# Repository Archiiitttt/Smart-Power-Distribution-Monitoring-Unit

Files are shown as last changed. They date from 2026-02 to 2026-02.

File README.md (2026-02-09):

# Smart Power Distribution & Monitoring Unit ⚡

## 📖 Overview
This project is an industrial-grade **Power Distribution and Monitoring Unit** designed to manage high-voltage DC inputs (up to 40V) for robotic or automotive applications. 

Unlike standard power distribution boards, this unit features **active intelligent monitoring**. It is centered around an **STM32F103 (ARM Cortex-M3)** to sample current and temperature data, providing a hardware platform capable of proactive system shutdown before thermal runaway or over-current events occur.

### 🎯 Key Capabilities
* **Wide Input Range:** Designed to handle **12V–40V DC** input with dedicated surge protection.
* **Smart Protection:** Features **Reverse Polarity Protection** using a P-Channel MOSFET (IRF4905) to minimize voltage drop compared to traditional diode-based solutions.
* **High-Power Switching:** Capable of driving high-current external loads via an **IRFP4468 MOSFET** and a dedicated **TC4427 Gate Driver**.
* **Integrated Telemetry:** Supports power consumption monitoring via a **1mΩ Shunt + INA180 Amplifier** and thermal tracking through a **6-zone NTC matrix**.

---

## ⚙️ System Architecture
The hardware architecture is divided into four main functional stages: **Protection, Regulation, Control, and Actuation**.

### 1. Power Stage
* **Input Protection:** Includes an automotive blade fuse and TVS Diode (D3) to clamp voltage spikes.
* **Reverse Polarity:** Implemented via **IRF4905** (Q1) for high-efficiency protection.
* **Regulation Logic:** Two-stage step-down architecture:
    1.  **Buck Converter (U1 - LM2596S-ADJ):** Steps 40V down to 12V for the Gate Driver.
    2.  **LDO (U2 - AMS1117-3.3):** Steps 12V down to 3.3V for the MCU and sensor suite.

### 2. Control & Sensing
* **Microcontroller:** Powered by an **STM32F103C8Tx** (U5).
* **Current Monitoring:** High-side sensing using an **INA180A1** (U3) amplifier across a **1mΩ shunt resistor** (R10).
* **Thermal Monitoring:** Features **6x NTC Thermistors** (TH1-TH6) placed at critical points for system-wide temperature tracking.

---

## 🔌 Hardware Specifications

| Parameter | Value | Component |
| :--- | :--- | :--- |
| **Input Voltage** | 12V - 40V DC | XT60 / Terminal Block |
| **Logic Voltage** | 3.3V | AMS1117-3.3 |
| **Gate Drive Voltage** | 12V | TC4427VOA |
| **Main Switch** | 100V / 195A (Max) | IRFP4468PbF |
| **Current Sense** | High-Side, Analog | INA180 + 1mΩ Shunt |
| **Protection** | Reverse Polarity, Fuse, TVS | IRF4905, SMBJ43A |

---

## 🛠️ PCB Design (KiCad)
The PCB design focuses on high-current integrity and thermal management.

### Design Considerations:
* **Trace Width:** Critical high-current paths utilize **polygons and copper pours** to handle high amperage without excessive heat generation.
* **Thermal Management:** Integrated thermal vias under the LDO and MOSFETs to facilitate heat dissipation to the ground plane.
* **Noise Reduction:** Optimized placement of decoupling capacitors (C2, C3, C11) near the STM32 and high-speed driver pins to minimize switching noise.

---

## 📂 Repository Structure

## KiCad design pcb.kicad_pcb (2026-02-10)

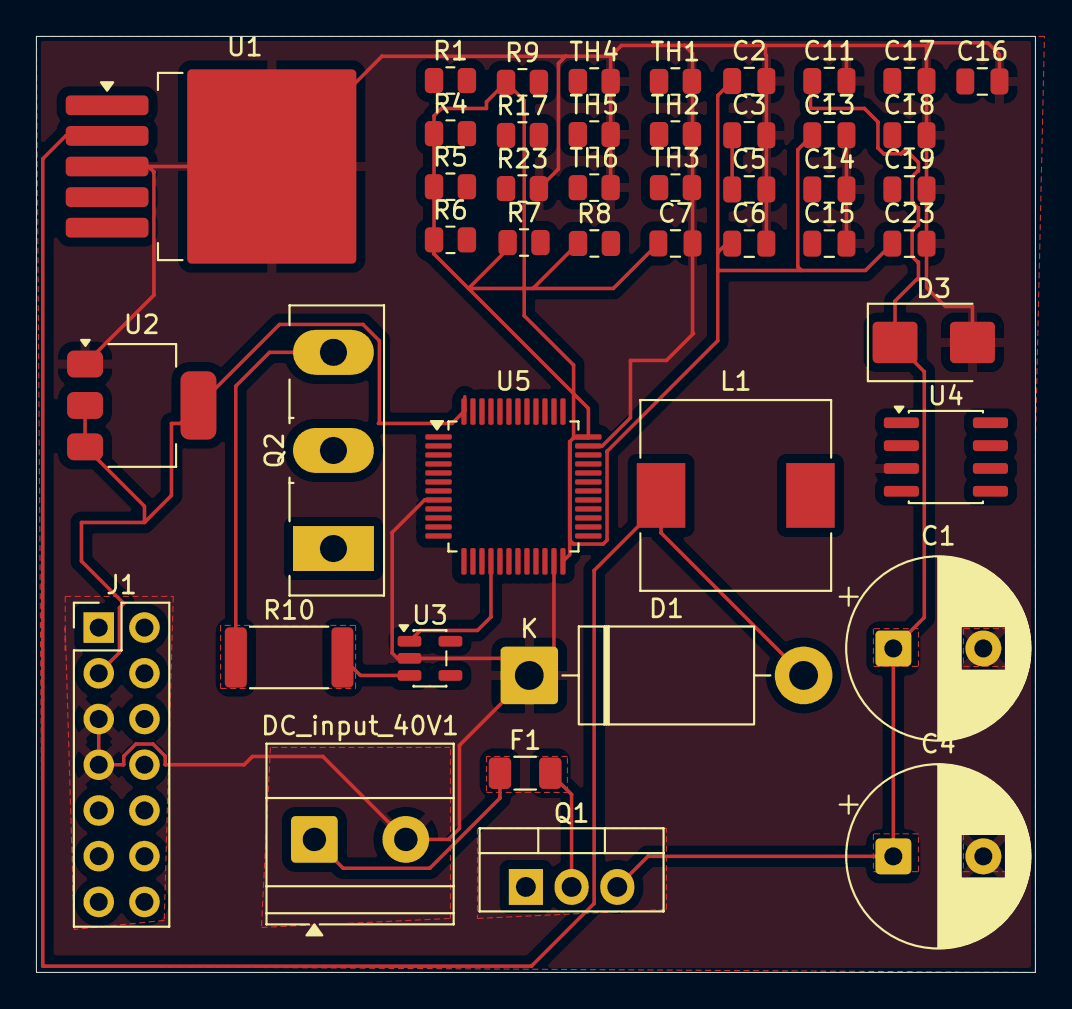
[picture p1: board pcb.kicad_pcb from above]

Board: 2 copper layers, 55.5 x 52.0 mm, 45 parts (0 on the bottom side), 23 nets.

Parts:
C1: 470uf; CP_Radial_D10.0mm_P5.00mm
C2, C3, C7, C11, C13, C23: 0.1uf; C_0805_2012Metric
C4: 220uf; CP_Radial_D10.0mm_P5.00mm
C5: 330uf; C_0805_2012Metric
C6: 10uf; C_0805_2012Metric
C14, C15, C16, C17, C18, C19: 100nF; C_0805_2012Metric
D1: 1N5822; D_DO-201AD_P15.24mm_Horizontal
D3: D_TVS; D_SMB
DC_input_40V1: Conn_01x02; TerminalBlock_Phoenix_MKDS-1,5-2-5.08_1x02_P5.08mm_Horizont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
F1: Fuse_Small; Fuse_1206_3216Metric
J1: Conn_ST_STDC14; PinHeader_2x07_P2.54mm_Vertical
L1: 68uh; L_10.4x10.4_H4.8
Q1: IRF4905; TO-220-3_Vertical
Q2: IRFP4468PbF; TO-247-3_Vertical
R1, R4, R5, R6, R7, R8, R9: 10K; R_0805_2012Metric
R10: 1m; R_2512_6332Metric
R17: 10; R_0805_2012Metric
R23: 100K; R_0805_2012Metric
TH1, TH2, TH3, TH4, TH5, TH6: 10K; R_0805_2012Metric
U1: LM2596S-ADJ; TO-263-5_TabPin3
U2: AMS1117-3.3; SOT-223-3_TabPin2
U3: INA180A1; SOT-23-5
U4: TC4427xOA; SOIC-8_3.9x4.9mm_P1.27mm
U5: STM32F103C8Tx; LQFP-48_7x7mm_P0.5mm

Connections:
/+3V3: C2.1, C6.1, C7.1, C13.1, C23.1, J1.3 (VCC), R4.1, R5.1, R6.1, R7.1, R8.1, R9.1, U2.2 (VO), U2.3 (VI), U5.24 (VDD), U5.36 (VDD), U5.48 (VDD)
/+12V: C3.1, C5.1, L1.2, U4.6 (V_{DD})
GND: C1.2, C2.2, C3.2, C4.2, C5.2, C6.2, C7.2, C11.2, C13.2, C14.2, C15.2, C16.2, C17.2, C18.2, C19.2, C23.2, D1.1 (K), D3.2 (A2), DC_input_40V1.2, J1.5 (GND), J1.7 (GND), R23.2, TH1.2, TH2.2, TH3.2, TH4.2, TH5.2, TH6.2, U1.3 (GND), U2.1 (GND), U3.2 (GND), U4.3 (GND), U5.8 (VSSA), U5.23 (VSS), U5.35 (VSS), U5.47 (VSS)
unnamed: D1.2 (A), L1.1, U1.2 (OUT)
unnamed: C1.1, C4.1, C11.1, D3.1 (A1), Q1.3 (S), U1.1 (VIN)
unnamed: DC_input_40V1.1, F1.1
unnamed: J1.6 (JCLK/SWCLK), U5.3 (PC14)
unnamed: J1.4 (JTMS/SWDIO), U5.2 (PC13)
unnamed: J1.12 (~RST), R1.2
unnamed: F1.2, Q1.2 (D)
unnamed: Q2.1 (G), R17.2, R23.1
unnamed: Q2.3 (S), R10.1
unnamed: R10.2, U3.3 (+)
unnamed: U4.2 (IN_A), U5.29 (PA8)
unnamed: R17.1, U4.7 (OUT_A)
unnamed: R1.1, U5.7 (NRST)
unnamed: C14.1, R4.2, TH1.1, U5.10 (PA0)
unnamed: C15.1, R7.2, TH2.1, U5.11 (PA1)
unnamed: C17.1, R5.2, TH3.1, U5.12 (PA2)
unnamed: C18.1, R8.2, TH4.1, U5.13 (PA3)
unnamed: C16.1, R6.2, TH5.1, U5.14 (PA4)
unnamed: C19.1, R9.2, TH6.1, U5.15 (PA5)
unnamed: U3.1, U5.16 (PA6)
